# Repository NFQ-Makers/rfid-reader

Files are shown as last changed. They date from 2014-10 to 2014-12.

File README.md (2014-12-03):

RFID Reader
===========

A not so simple 125KHz rfid reader based on a ATTiny and EM4095

Build around a single timer (Timer0), uses two interrupts pin change and INT0
Manchester code decoding based on Timing approach. Base clock 16.5MHz.

Input
-------
- **PB2** - Input of Card data (after EM)

Outputs
-------
- **PB1** - EM4095 disable / Red led
- **PB0** - Green led

Quite interseting
------
This device tries to calibrate itself to 16.5MHz by measuring usb packet lenght. It also stores its last calibration
value to EEPROM byte address 0 (first byte as this can be read by avrdude)

Also never compile this with optimization level -O3 as USB will not work. -Os (size) seems to be ok

Makefile
------
For convinience there is a make file with instructions:
- **make** - compiles the compileables
- **make flash** - flashes flash with a flash file
- **make fuse** - tries to fuse the fuses
- **make install** - compiles, flashes, fuses

PCB
------
Double layer SMD in KiCad format

AVR Memory Usage
------
```
Device: attiny85

Program:    2456 bytes (30.0% Full)
(.text + .data + .bootloader)

Data:         70 bytes (13.7% Full)
(.data + .bss + .noinit)
```
---
**Thanks to:**

- [Vassilis Serasidis](http://www.serasidis.gr/circuits/RFID_reader/125kHz_RFID_reader.htm) - Manchester code ideas
- [V-USB](http://www.obdev.at/products/vusb/index.html) - Software USB support :)

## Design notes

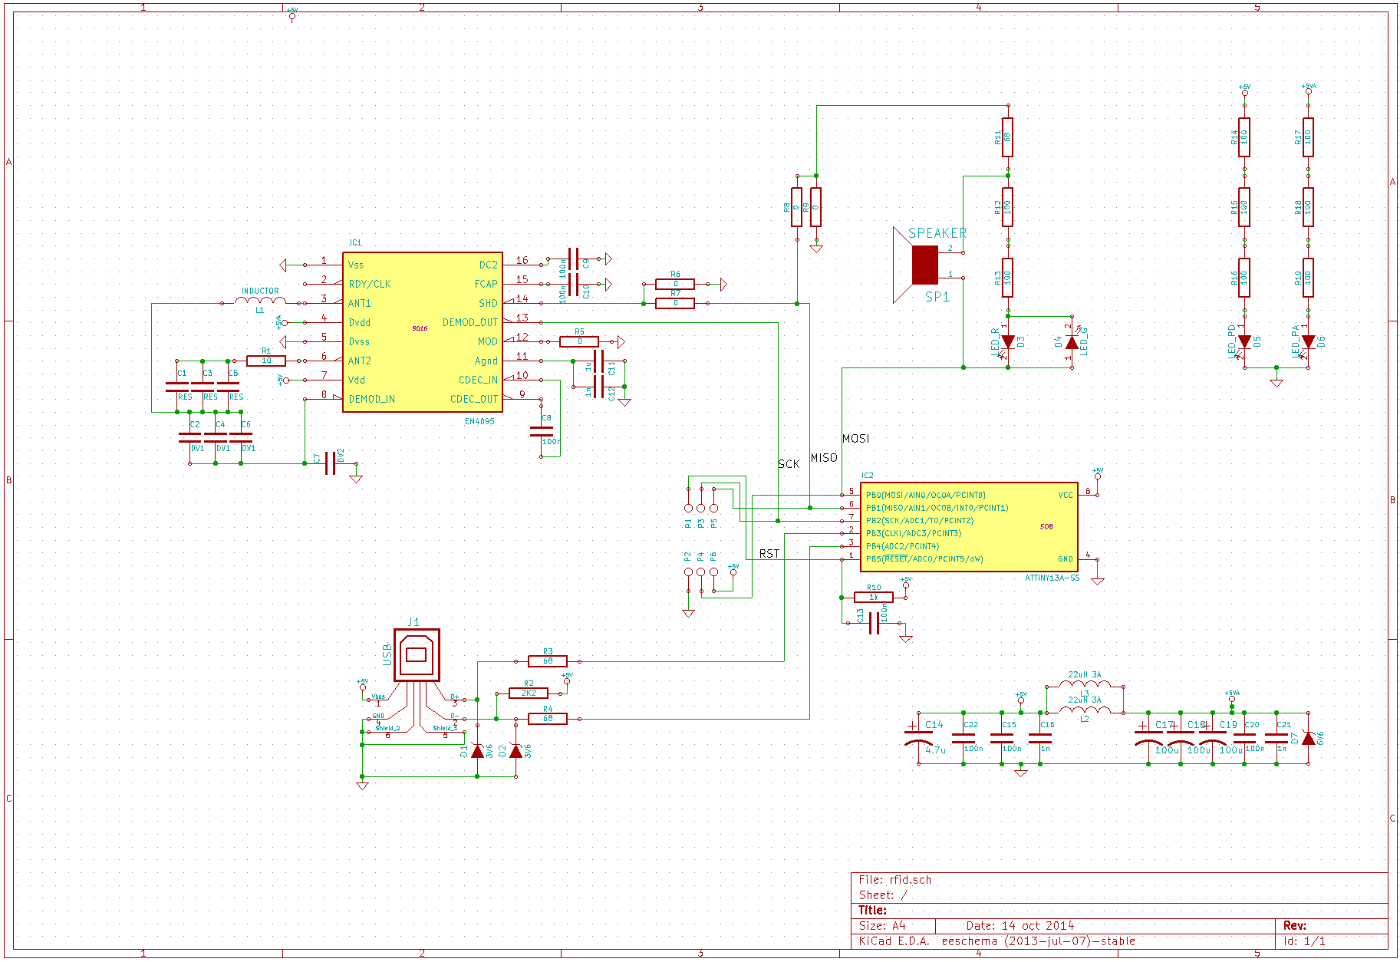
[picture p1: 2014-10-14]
images/sch.png

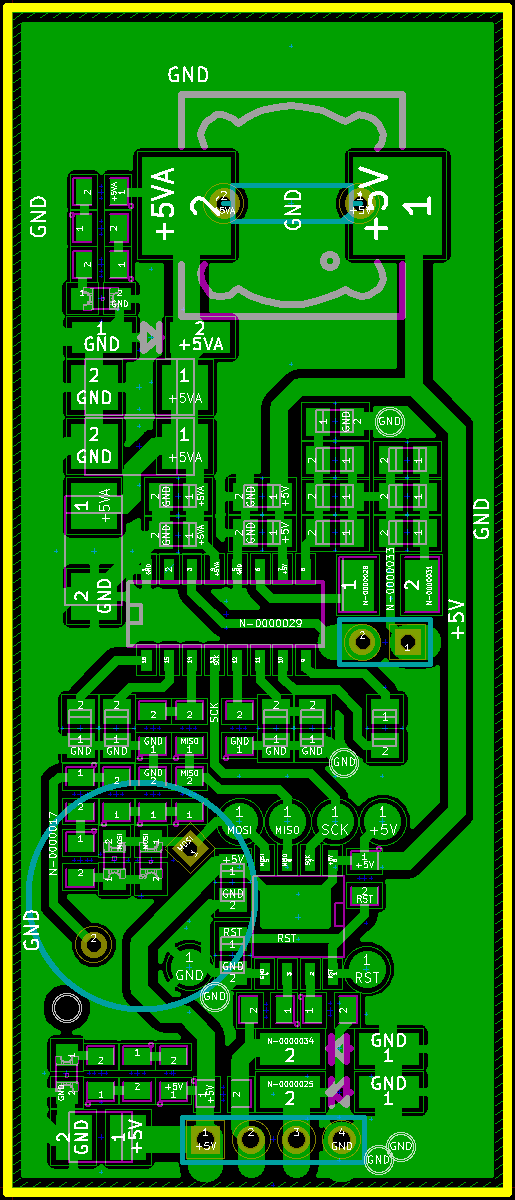
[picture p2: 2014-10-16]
images/pcb.png

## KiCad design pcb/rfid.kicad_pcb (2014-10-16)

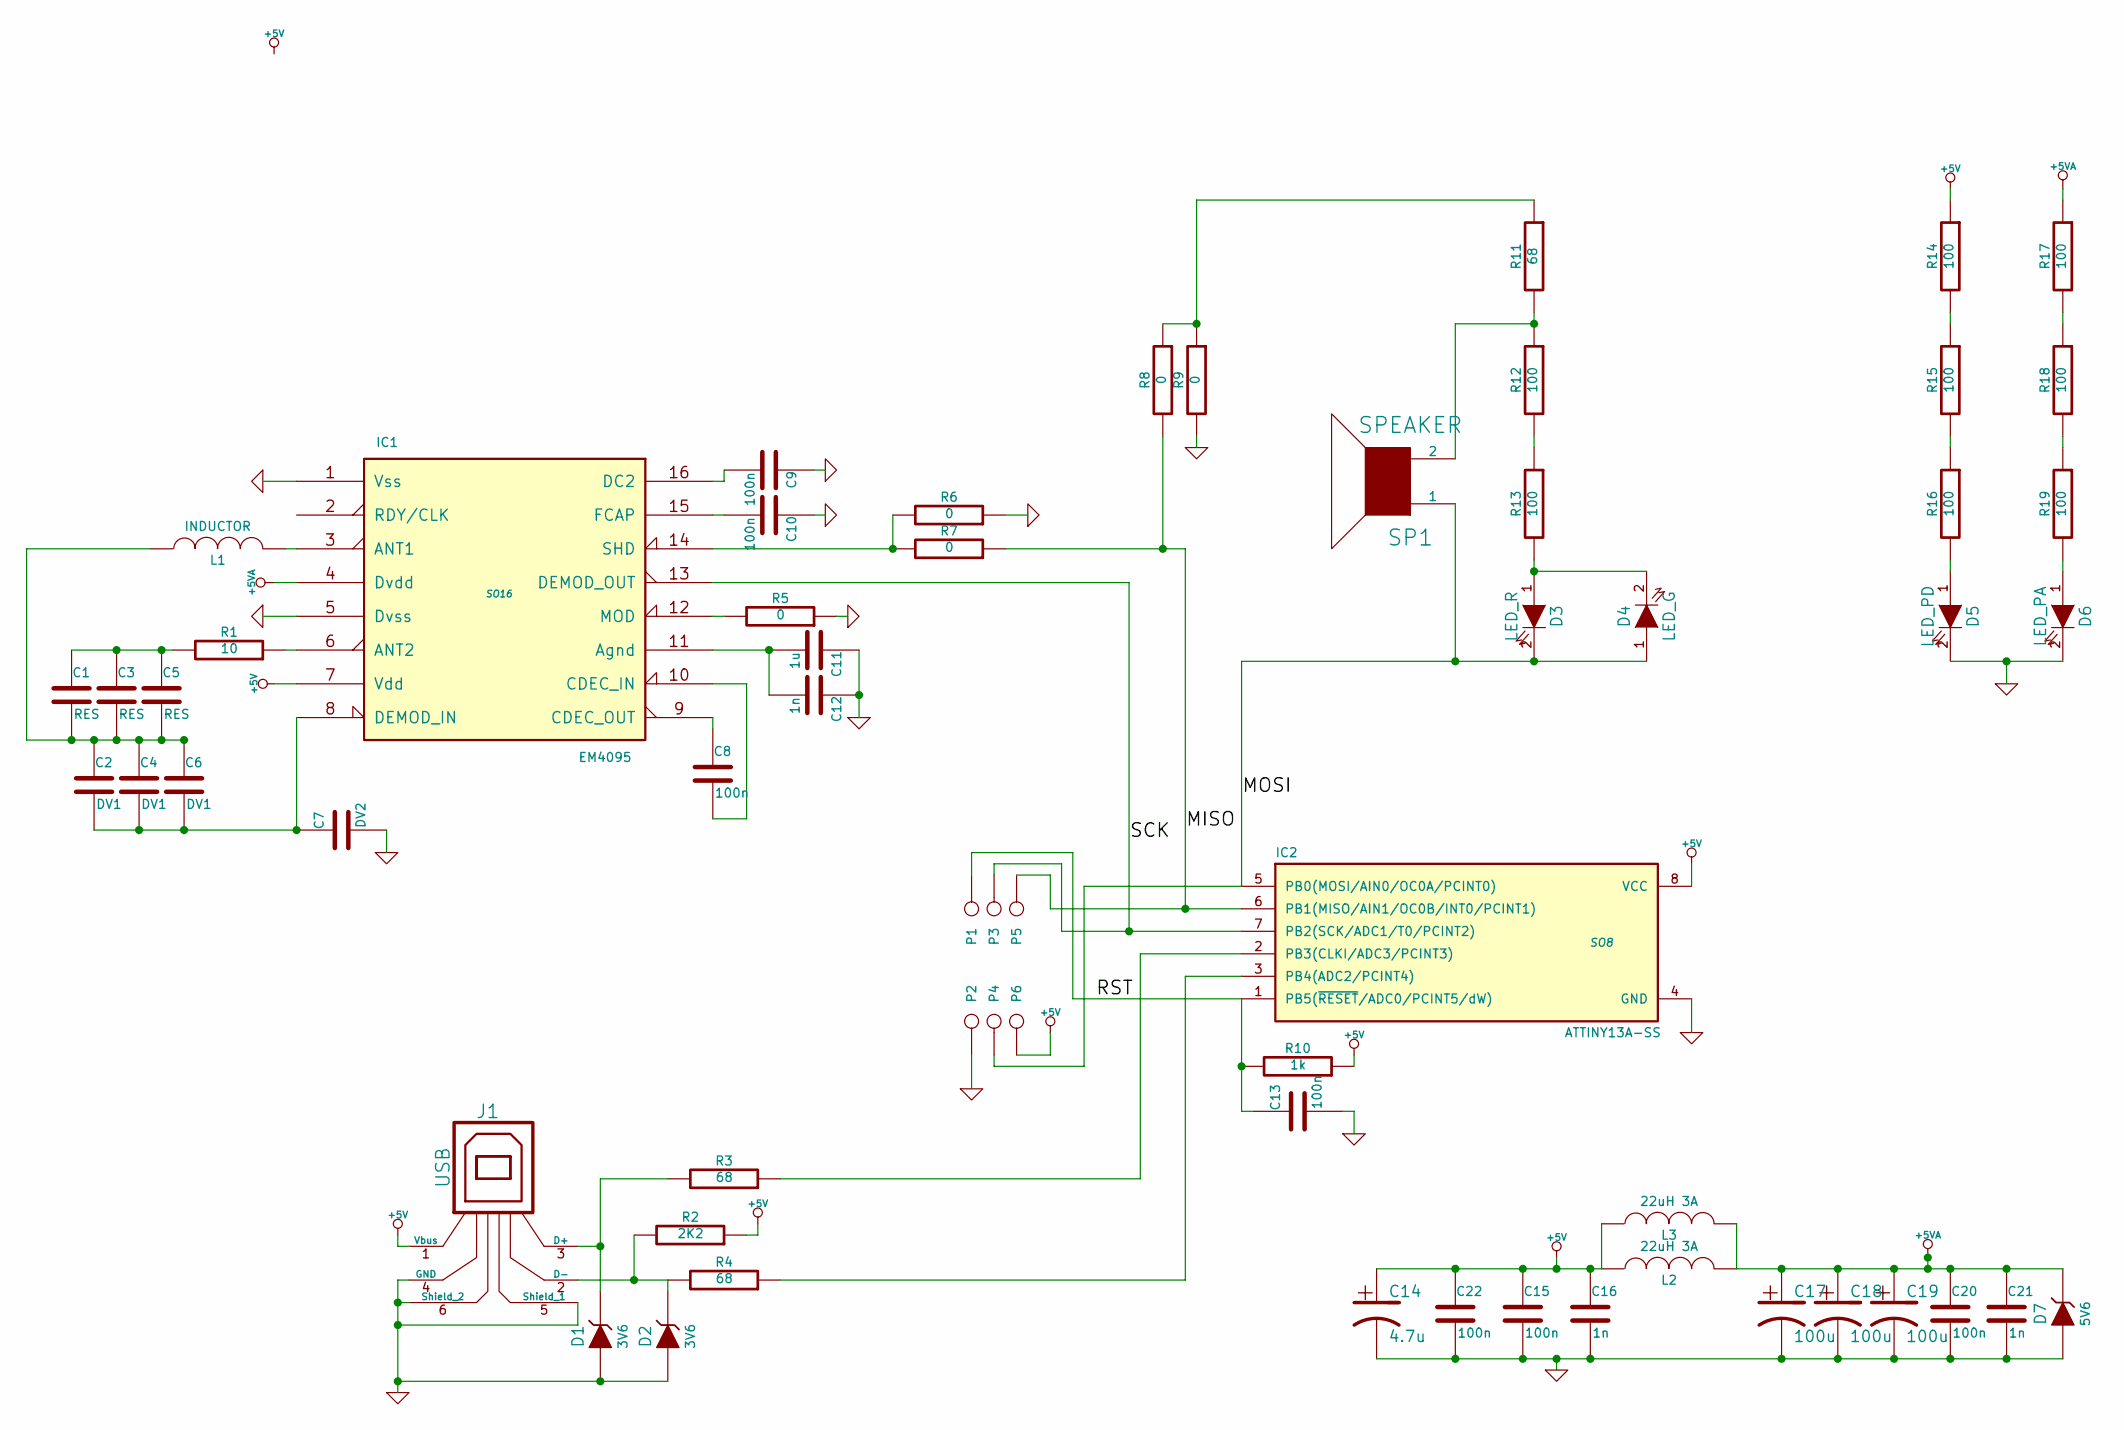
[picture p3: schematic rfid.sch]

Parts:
C1, C3, C5: RES
C2, C4, C6: DV1
C7: DV2
C8, C9, C10, C13, C15, C20, C22: 100n
C11: 1u
C12, C16, C21: 1n
C14: 4.7u
C17, C18, C19: 100u
D1, D2: 3V6
D3: LED_R
D4: LED_G
D5: LED_PD
D6: LED_PA
D7: 5V6
IC1: EM4095; SO16
IC2: ATTINY13A-SS; SO8
J1: USB
L1: INDUCTOR
L2, L3: 22uH 3A
P1, P2, P3, P4, P5, P6: CONN_1
R1: 10
R2: 2K2
R3, R4, R11: 68
R5, R6, R7, R8, R9: 0
R10: 1k
R12, R13, R14, R15, R16, R17, R18, R19: 100
SP1: SPEAKER

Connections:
+5V: C14.1, C15.1, C16.1, C22.1, IC1.7 (Vdd), IC2.8 (VCC), J1.1 (Vbus), L2.1, L3.1, P6.1, R2.1, R10.1, R14.1
+5VA: C17.1, C18.1, C19.1, C20.1, C21.1, D7.2 (K), IC1.4 (Dvdd), L2.2, L3.2, R17.1
/MISO: IC2.6 (PB1(MISO/AIN1/OC0B/INT0/PCINT1)), P5.1, R7.1, R8.2
/MOSI: D3.2 (K), D4.1 (A), IC2.5 (PB0(MOSI/AIN0/OC0A/PCINT0)), P4.1, SP1.1
/RST: C13.1, IC2.1 (PB5(~RESET~/ADC0/PCINT5/dW)), P1.1, R10.2
/SCK: IC1.13 (DEMOD_OUT), IC2.7 (PB2(SCK/ADC1/T0/PCINT2)), P3.1
GND: C7.2, C9.1, C10.1, C11.1, C12.1, C13.2, C14.2, C15.2, C16.2, C17.2, C18.2, C19.2, C20.2, C21.2, C22.2, D1.1 (A), D2.1 (A), D5.2 (K), D6.2 (K), D7.1 (A), IC1.1 (Vss), IC1.5 (Dvss), IC2.4 (GND), J1.4 (GND), J1.5 (Shield_1), J1.6 (Shield_2), P2.1, R5.1, R6.1, R9.2
unnamed: R17.2, R18.1
unnamed: R14.2, R15.1
unnamed: D6.1 (A), R19.2
unnamed: D5.1 (A), R16.2
unnamed: IC1.14 (SHD), R6.2, R7.2
unnamed: R15.2, R16.1
unnamed: R18.2, R19.1
unnamed: IC2.3 (PB4(ADC2/PCINT4)), R4.1
unnamed: IC2.2 (PB3(CLKI/ADC3/PCINT3)), R3.1
unnamed: C11.2, C12.2, IC1.11 (Agnd)
unnamed: C8.1, IC1.9 (CDEC_OUT)
unnamed: R11.2, R12.1, SP1.2
unnamed: R8.1, R9.1, R11.1
unnamed: R12.2, R13.1
unnamed: D3.1 (A), D4.2 (K), R13.2
unnamed: C9.2, IC1.16 (DC2)
unnamed: C8.2, IC1.10 (CDEC_IN)
unnamed: D1.2 (K), J1.3 (D+), R3.2
unnamed: C10.2, IC1.15 (FCAP)
unnamed: IC1.12 (MOD), R5.2
unnamed: IC1.6 (ANT2), R1.1
unnamed: IC1.3 (ANT1), L1.2
unnamed: C1.1, C3.1, C5.1, R1.2
unnamed: C2.2, C4.2, C6.2, C7.1, IC1.8 (DEMOD_IN)
unnamed: C1.2, C2.1, C3.2, C4.1, C5.2, C6.1, L1.1
unnamed: D2.2 (K), J1.2 (D-), R2.2, R4.2

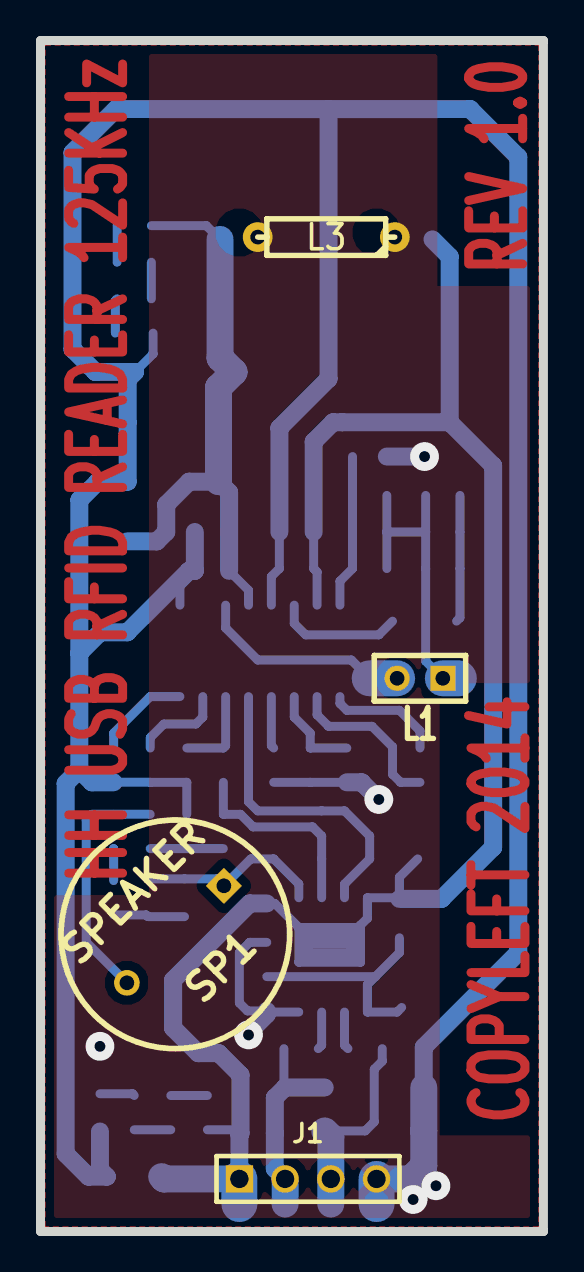
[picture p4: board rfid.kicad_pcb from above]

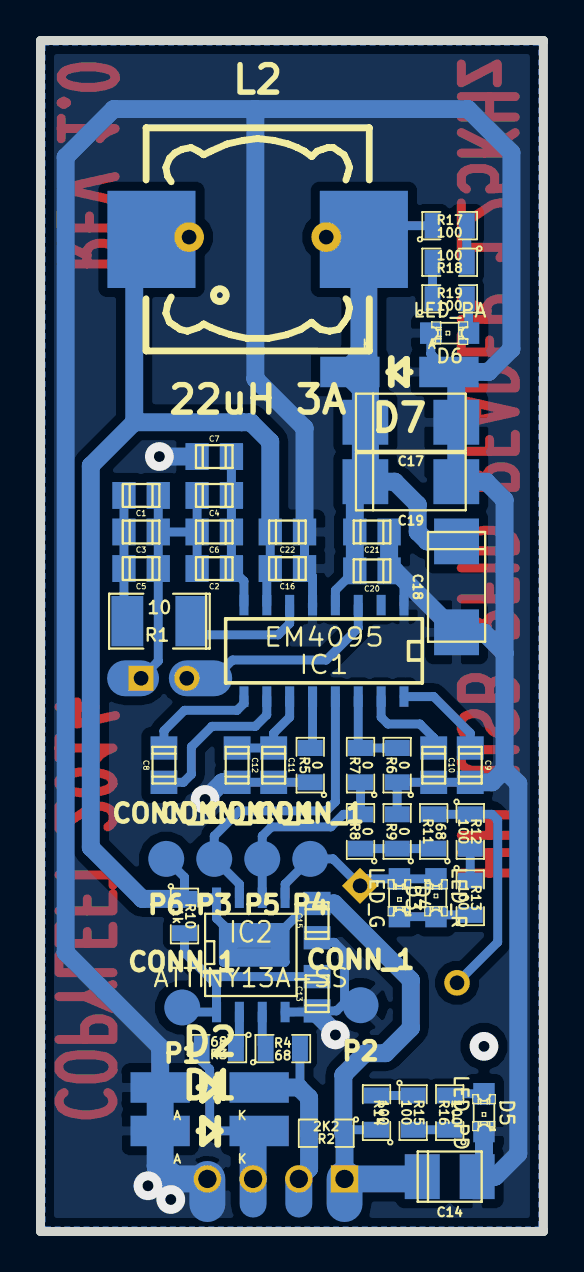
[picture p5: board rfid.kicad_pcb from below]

Board: 2 copper layers, 27.9 x 66.2 mm, 61 parts (57 on the bottom side), 33 nets.

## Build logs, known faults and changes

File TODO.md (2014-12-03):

# TODO regarding USB support
1. Current setup work on hand tuned OSSCAL value. firmware loads it from EEPROM address **0** (first byte). It can be written using avr dude: `avrdude -c usbasp -p attiny85 -U eeprom:w:value:m` where value is ant int. A working example is based around 117. OSSCAL value has 2 regions 0-127 and 128-255 these regions do overlap so going above 127 doesn't mean that freacuency will be bigger than 127. More can be red in attiny datasheet regarding OSCCAL register description.
  * Freaquency of specific OSCCAL value can be checked in crude method. Set required frequency in the Makefile and add code in `main()`
  ```
  OSSCAL = 115;
  PORTB |= (1 << PINB1);
  while (1) {
      PORTB ^= 1;
      _delay_ms(1);
  }
  return 0;
  ```
  Then just add a probe on green led output and check if high or low width is 1ms if its lower decreas OSSCAL and repeat, if its higher increase.

2. A proper way would be to decrease the clock to **16.5MHz** instead of **20**. The reason behind that is 16.5Mhz can have deviations up to 1% and on 20MHz only 200ppm is allowed. Also using 16.5MHz an auto calibration of OSCCAL can be introduces (well with some modification it can probably be done on 20MHz as well)

  To achieve that some things needs to be changed
  * First change the value of clock speed to **16500000** in Makefile of if you using any IDE change the clock speed in its settings
  * Try the hand tunning of OSCCAL as described above to see if you can make it work on this freq. (Only usb part will work with lowered frequency)
  * Next step would be to integrate auto tunning by first uncomenting block in **usbconfig.h**
  ```
#ifndef __ASSEMBLER__
#ifndef __ASSEMBLER__
      extern void usbEventResetReady(void);
#endif
#define USB_RESET_HOOK(isReset) if(!isReset){usbEventResetReady();}
  ```
  * in **usbconfig.h** enable `USB_CFG_HAVE_MEASURE_FRAME_LENGTH`
  * Next in **RFID.c** you should add method `usbEventReset()` which will do all the calibration. It can be taken from [EasyLoger](http://www.obdev.at/products/vusb/easylogger.html)
  * If you make `usbEventReset()` yourself then edit **RFID.c** `main()` method and change OSSCAL loading (first lines).
  * This should fix USB issues. The next part is to adapt Manchester decoding to new frequency. In **Reader.c** there is a method `uint8_t getPeriod(uint8_t cycles)` which desides on periods between 2 edge triggers on RF frontend output. Cycles are `Timer0` counts from `TCNT0` register. Now `Timer0` is configured with prescaler of **1024** meaning each 1024 cpu cycles `TCNT0` will be increased by **1**. So each value is about **61.2ms**
  * Tipical **T** range is around **256us** and **2T** is **512us**
  * First thing would be do decrease the prescaler of `Timer0`. Prescaler is set in **Reader.c**  Line 114 `TCCR0B |= 0b101;` . Be avare that if prescaler is to low, `TCNT0` will overflow as it is only 8bits long. So choose a proper value or implement overflow counting as well.
  * After `Timer0` prescaler will be changed next step is to tweak the T and 2T perdion valuesin **Reader.c** method `getPeriod()`
  * And thats all, **HAVE FUN!!**

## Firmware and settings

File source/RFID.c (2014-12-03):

#include <avr/io.h>
#include <avr/interrupt.h>
#include <util/delay.h>
#include <stdlib.h>
#include <stdio.h>

#include <avr/wdt.h>
#include <avr/eeprom.h>
#include <avr/pgmspace.h>

#include "Reader/Reader.h"
#include "usbdrv/usbdrv.h"

/************************************************************************/
/* Lets say something about what we are                                 */
/************************************************************************/
const PROGMEM char usbHidReportDescriptor[USB_CFG_HID_REPORT_DESCRIPTOR_LENGTH] = {
        0x05, 0x01,                    // USAGE_PAGE (Generic Desktop)
        0x09, 0x06,                    // USAGE (Keyboard)
        0xa1, 0x01,                    // COLLECTION (Application)
        0x05, 0x07,                    //   USAGE_PAGE (Keyboard)
        0x19, 0xe0,                    //   USAGE_MINIMUM (Keyboard LeftControl)
        0x29, 0xe7,                    //   USAGE_MAXIMUM (Keyboard Right GUI)
        0x15, 0x00,                    //   LOGICAL_MINIMUM (0)
        0x25, 0x01,                    //   LOGICAL_MAXIMUM (1)
        0x75, 0x01,                    //   REPORT_SIZE (1)
        0x95, 0x08,                    //   REPORT_COUNT (8)
        0x81, 0x02,                    //   INPUT (Data,Var,Abs)
        0x95, 0x01,                    //   REPORT_COUNT (1)
        0x75, 0x08,                    //   REPORT_SIZE (8)
        0x25, 0x65,                    //   LOGICAL_MAXIMUM (101)
        0x19, 0x00,                    //   USAGE_MINIMUM (Reserved (no event indicated))
        0x29, 0x65,                    //   USAGE_MAXIMUM (Keyboard Application)
        0x81, 0x00,                    //   INPUT (Data,Ary,Abs)
        0xc0                           // END_COLLECTION
    };

/************************************************************************/
/* USB TX Buffer data                                                   */
/************************************************************************/
static uchar     reportBuffer[2];

/************************************************************************/
/* HID seems to be controller by the usbdrv itself                      */
/************************************************************************/
uchar   usbFunctionSetup(uchar data[8])
{
    return 0;
}

/************************************************************************/
/* Delay with a tamed watchdog                                          */
/************************************************************************/
void smartDelay(uint16_t ms, uint8_t usb)
{
    while (ms) {
        wdt_reset();

        if (usb) {
            usbPoll();
        }

        _delay_us(990);
        ms--;
    }
}

/************************************************************************/
/* 16.5MHz calibration routine                                          */
/************************************************************************/
static void calibrateOscillator(void)
{
    uint8_t step = 128;
    uint8_t trialValue = 0;
    uint8_t optimumValue;
    int x, optimumDev, targetValue = (unsigned)(1499 * (double)F_CPU / 10.5e6 + 0.5);

    /* do a binary search: */
    do{
        OSCCAL = trialValue + step;
        x = usbMeasureFrameLength();    /* proportional to current real frequency */
        if(x < targetValue)             /* frequency still too low */
            trialValue += step;
        step >>= 1;
    }while(step > 0);

    /* We have a precision of +/- 1 for optimum OSCCAL here */
    /* now do a neighborhood search for optimum value */
    optimumValue = trialValue;
    optimumDev = x; /* this is certainly far away from optimum */

    for(OSCCAL = trialValue - 1; OSCCAL <= trialValue + 1; OSCCAL++){
        x = usbMeasureFrameLength() - targetValue;
        if(x < 0)
            x = -x;
        if(x < optimumDev){
            optimumDev = x;
            optimumValue = OSCCAL;
        }
    }
    OSCCAL = optimumValue;
}

/************************************************************************/
/* USB reset event hook                                                 */
/************************************************************************/
void usbEventResetReady(void)
{
    cli();
    calibrateOscillator();
    sei();
    eeprom_write_byte(0, OSCCAL);   /* store the calibrated value in EEPROM */
}

/************************************************************************/
/* Fill in USB HID report and send it                                   */
/************************************************************************/
void sendReport(uchar c)
{
    reportBuffer[0] = 0; // No additional modifiers

    if (c == 48) {
        c = 39;
    } else if (c != 0) {
        c -= 19;
    }

    reportBuffer[1] = c;

    usbSetInterrupt(reportBuffer, sizeof(reportBuffer));
}

/************************************************************************/
/* Lets rock & roll                                                     */
/************************************************************************/
int main(void)
{
    // In case we have a reset without USB reset event load last calibrated value
    uint8_t calibrationValue = eeprom_read_byte(0);
    if (calibrationValue != 0xFF) {
        OSCCAL = calibrationValue;
    }

    // A short watchdog
    wdt_enable(WDTO_120MS);

    // USB init needs to be called before interrupts are enabled
    usbInit();

    // Simulate unpluging device to host
    usbDeviceDisconnect();

    // PINB1 AND PINB0 as outputs
    DDRB |= 0b11;

    // Turn of RF front-end, leds off
    PORTB |= 0b11;

    // Delay to give some time for host to process device removal
    smartDelay(300, 0);

    // Enable interrupts
    sei();

    // Simulate device connection in host and delay to process.
    // Well if windows will install any drivers it will need more that 1s
    // but this is just a safeguard for normal operation
    usbDeviceConnect();
    smartDelay(1000, 1);

    // Start checking for RF tags
    startReader();

    while (1) {
        // We are alive. Aren't we?
        wdt_reset();
        usbPoll();

        // We got a user ID ready (card red duhh....)
        if (rStatus & (1 << R_ID_READY)) {
            // Some string and number porn
            char idString[12];
            uint8_t pos = 0;

            sprintf(idString, "%010lu", idData);
            idString[10] = 59; // ENTER 19 will be subtracted
            idString[11] = 0; // All keys are released

            // Turn red led and a sub woofer - BUSY! USB transmission in progress
            PORTB &= ~1;
            uint8_t sendEmpty = 0;

            while (pos < 12 || sendEmpty) {
                if(usbInterruptIsReady()){ // We can send another report
                    wdt_reset();
                    if (sendEmpty) {
                        // No buttons pressed, we need this to be not affected by the host
                        // keyboard key down delay
                        sendReport(0);
                        sendEmpty = 0;
                        continue;
                    } else {
                        sendReport(idString[pos]);
                        pos++;
                        sendEmpty = 1;
                    }
                }
            }

            // Turn off that buzzer, please!!
            PORTB |= 1;

            // Some delay to minimize double reads
            smartDelay(400, 1);
            startReader();
        }
    }

    return 0;
}

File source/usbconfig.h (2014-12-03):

/* Name: usbconfig.h
 * Project: AVR USB driver
 * Author: Christian Starkjohann
 * Creation Date: 2007-06-23
 * Tabsize: 4
 * Copyright: (c) 2007 by OBJECTIVE DEVELOPMENT Software GmbH
 * License: GNU GPL v2 (see License.txt) or proprietary (CommercialLicense.txt)
 * This Revision: $Id$
 */

#ifndef __usbconfig_h_included__
#define __usbconfig_h_included__

/* ---------------------------- Hardware Config ---------------------------- */

#define USB_CFG_IOPORTNAME      B
/* This is the port where the USB bus is connected. When you configure it to
 * "B", the registers PORTB, PINB and DDRB will be used.
 */
#define USB_CFG_DMINUS_BIT      4
/* This is the bit number in USB_CFG_IOPORT where the USB D- line is connected.
 * This may be any bit in the port.
 */
#define USB_CFG_DPLUS_BIT       3
/* This is the bit number in USB_CFG_IOPORT where the USB D+ line is connected.
 * This may be any bit in the port. Please note that D+ must also be connected
 * to interrupt pin INT0!
 */
#define USB_CFG_CLOCK_KHZ       (F_CPU/1000)
/* Clock rate of the AVR in MHz. Legal values are 12000, 16000 or 16500.
 * The 16.5 MHz version of the code requires no crystal, it tolerates +/- 1%
 * deviation from the nominal frequency. All other rates require a precision
 * of 2000 ppm and thus a crystal!
 * Default if not specified: 12 MHz
 */

/* ----------------------- Optional Hardware Config ------------------------ */

/* #define USB_CFG_PULLUP_IOPORTNAME   D */
/* If you connect the 1.5k pullup resistor from D- to a port pin instead of
 * V+, you can connect and disconnect the device from firmware by calling
 * the macros usbDeviceConnect() and usbDeviceDisconnect() (see usbdrv.h).
 * This constant defines the port on which the pullup resistor is connected.
 */
/* #define USB_CFG_PULLUP_BIT          4 */
/* This constant defines the bit number in USB_CFG_PULLUP_IOPORT (defined
 * above) where the 1.5k pullup resistor is connected. See description
 * above for details.
 */

/* --------------------------- Functional Range ---------------------------- */

#define USB_CFG_HAVE_INTRIN_ENDPOINT    1
/* Define this to 1 if you want to compile a version with two endpoints: The
 * default control endpoint 0 and an interrupt-in endpoint 1.
 */
#define USB_CFG_HAVE_INTRIN_ENDPOINT3   0
/* Define this to 1 if you want to compile a version with three endpoints: The
 * default control endpoint 0, an interrupt-in endpoint 1 and an interrupt-in
 * endpoint 3. You must also enable endpoint 1 above.
 */
#define USB_CFG_IMPLEMENT_HALT          0
/* Define this to 1 if you also want to implement the ENDPOINT_HALT feature
 * for endpoint 1 (interrupt endpoint). Although you may not need this feature,
 * it is required by the standard. We have made it a config option because it
 * bloats the code considerably.
 */
#define USB_CFG_INTR_POLL_INTERVAL      10
/* If you compile a version with endpoint 1 (interrupt-in), this is the poll
 * interval. The value is in milliseconds and must not be less than 10 ms for
 * low speed devices.
 */
#define USB_CFG_IS_SELF_POWERED         0
/* Define this to 1 if the device has its own power supply. Set it to 0 if the
 * device is powered from the USB bus.
 */
#define USB_CFG_MAX_BUS_POWER           50
/* Set this variable to the maximum USB bus power consumption of your device.
 * The value is in milliamperes. [It will be divided by two since USB
 * communicates power requirements in units of 2 mA.]
 */
#define USB_CFG_IMPLEMENT_FN_WRITE      0
/* Set this to 1 if you want usbFunctionWrite() to be called for control-out
 * transfers. Set it to 0 if you don't need it and want to save a couple of
 * bytes.
 */
#define USB_CFG_IMPLEMENT_FN_READ       0
/* Set this to 1 if you need to send control replies which are generated
 * "on the fly" when usbFunctionRead() is called. If you only want to send
 * data from a static buffer, set it to 0 and return the data from
 * usbFunctionSetup(). This saves a couple of bytes.
 */
#define USB_CFG_IMPLEMENT_FN_WRITEOUT   0
/* Define this to 1 if you want to use interrupt-out (or bulk out) endpoint 1.
 * You must implement the function usbFunctionWriteOut() which receives all
 * interrupt/bulk data sent to endpoint 1.
 */
#define USB_CFG_HAVE_FLOWCONTROL        0
/* Define this to 1 if you want flowcontrol over USB data. See the definition
 * of the macros usbDisableAllRequests() and usbEnableAllRequests() in
 * usbdrv.h.
 */
/* #ifndef __ASSEMBLER__
 * extern void usbEventResetReady(void);
 * #endif
 * #define USB_RESET_HOOK(isReset)             if(!isReset){usbEventResetReady();}
 *
 * This macro is a hook if you need to know when an USB RESET occurs. It has
 * one parameter which distinguishes between the start of RESET state and its
 * end.
 */
#ifndef __ASSEMBLER__
    extern void usbEventResetReady(void);
#endif
#define USB_RESET_HOOK(isReset) if(!isReset){usbEventResetReady();}
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

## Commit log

2014-07-18 copying reader from project https://github.com/joinedforces/nekvailas_stalas
    [rfid.kicad_pcb, rfid.sch]
2014-07-18 adding USB stuff to use with v-usb
    [rfid.sch]
2014-09-12 replaced RF frontend with EM4095
    [rfid.sch]
2014-09-20 connecting attiny13 and adding schematics png
    [rfid.sch]
2014-09-20 associating footprints and minor schematics changes
    [rfid.sch]
2014-09-26 starting new pcb routing
    [rfid.kicad_pcb, rfid.sch]
2014-10-13 routing pcb with only few GND left unconnected
    [rfid.kicad_pcb]
2014-10-14 adding ISP pads to schematics
    [rfid.sch]
2014-10-14 finalising pcb routing
    [rfid.kicad_pcb]
2014-10-16 shrinking PCB and adding BOM
    [rfid.kicad_pcb]
2014-11-20 Some major changes
    Reduced base clock to 16.5MHz
    Added auto tune rutines for OSCCAL calibration
    Added key release event after each character
    Added leading 0's to the card number
    Delay changes (needs more work)
    Removed tune target from Makefile (as its not needed anymore)

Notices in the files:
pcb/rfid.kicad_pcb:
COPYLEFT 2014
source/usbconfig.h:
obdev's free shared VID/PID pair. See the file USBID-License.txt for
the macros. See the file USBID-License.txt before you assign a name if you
